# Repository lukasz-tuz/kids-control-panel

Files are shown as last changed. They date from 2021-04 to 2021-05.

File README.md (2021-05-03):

# kids-control-panel

This project is a spaceship-like control panel toy for kids (of all ages) allowing to:

* display characters from the alphanumeric keypad on the 7-segment display
* turn on LEDs in the 8x8 matrix when keys are pressed on the 4x4 keypad
* display some patterns using the 4-color LED bar
* use four tactile buttons to switch modes of operation for joystick and encoder:
  * control the LED bar
  * control the RGB LED's color
  * control LEDs on the 8x8 matrix
  
Repository contains FreeCAD designs for the casing (inteded for wood laser cutters), KiCAD schematics for the electronics part, and code for Arduino Uno R3 board.

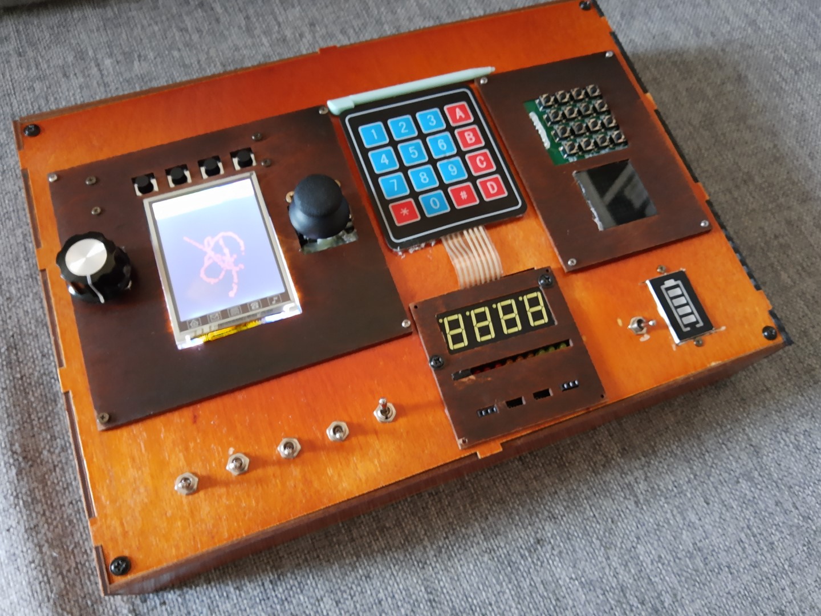
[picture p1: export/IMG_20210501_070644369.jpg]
Control panel Assembled control panel

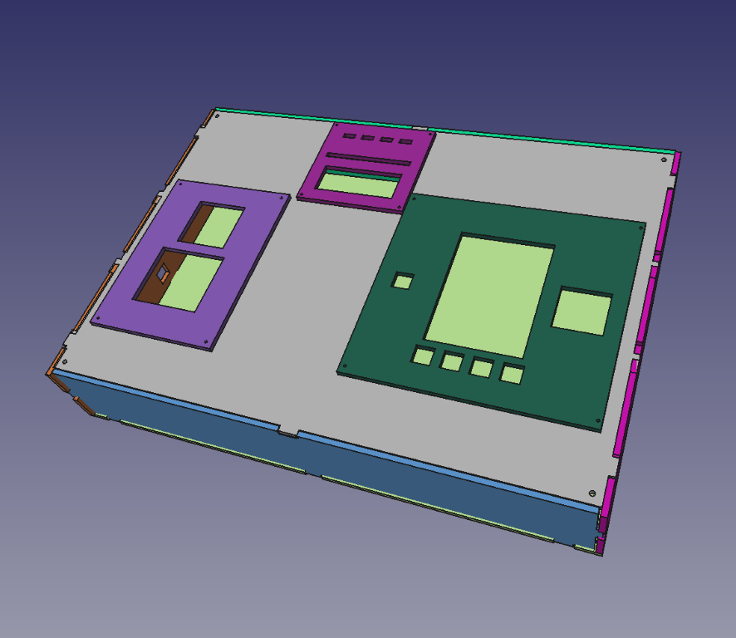
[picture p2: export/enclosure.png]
The casing Casing CAD design

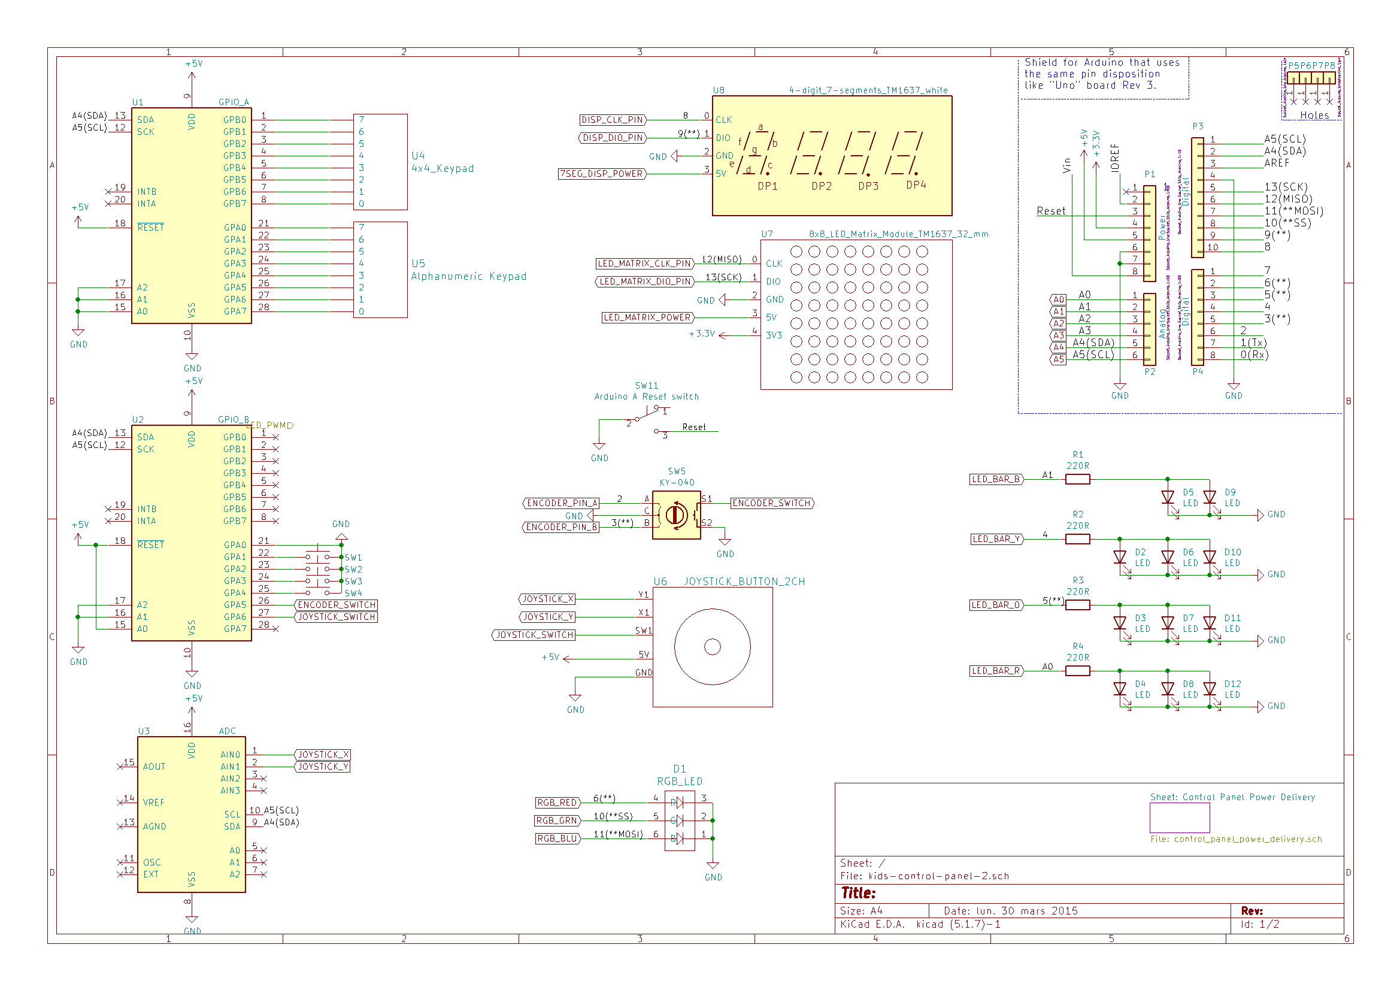
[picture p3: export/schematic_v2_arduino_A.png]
Schematic Schematic for Arduino wiring


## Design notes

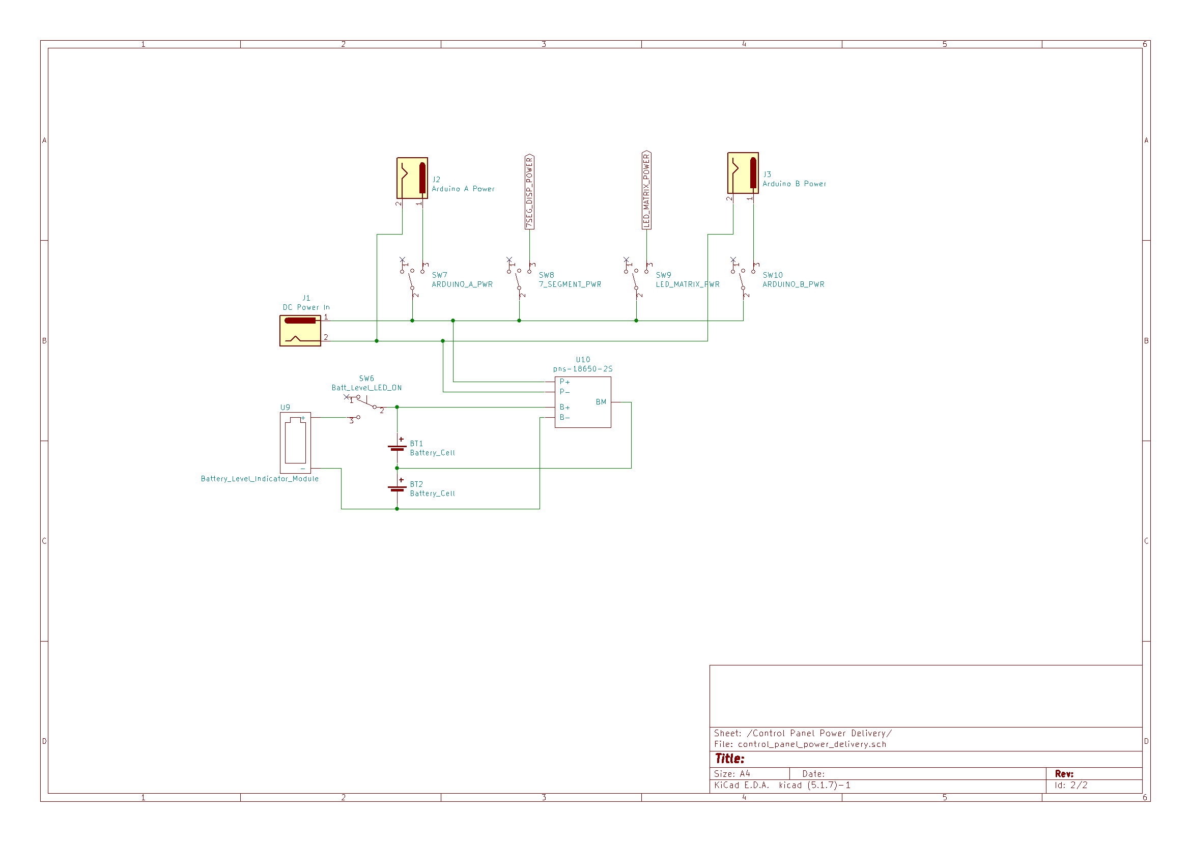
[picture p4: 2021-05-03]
export/schematic_power_connector.png

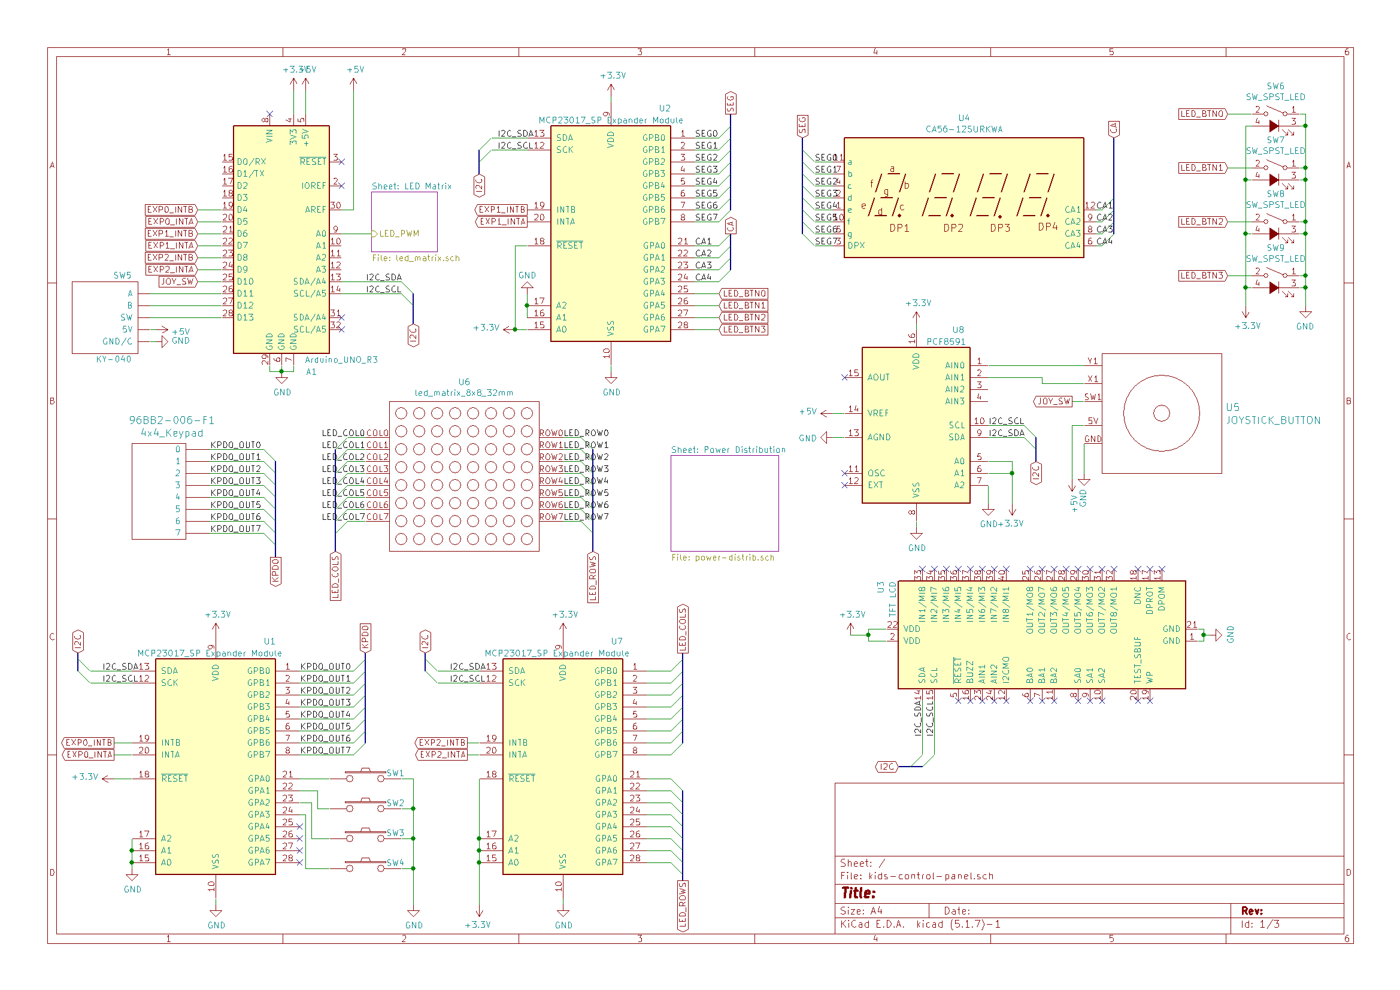
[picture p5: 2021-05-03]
export/schematic.png

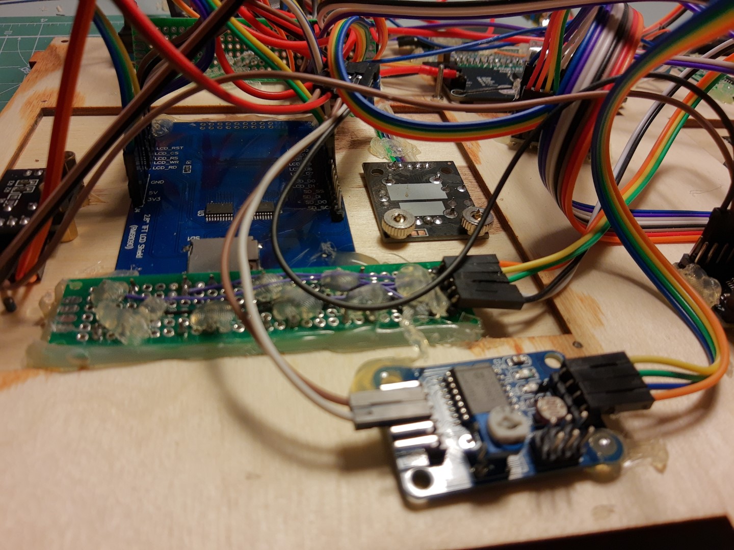
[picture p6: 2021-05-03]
export/IMG_20210430_232544490_MP.jpg

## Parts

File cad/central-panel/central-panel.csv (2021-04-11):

Comment | Designator | Footprint | LCSC
100pF | C1,C2 | Capacitor_SMD:C_0603_1608Metric | C1635
100uF | C3 | Capacitor_SMD:C_1206_3216Metric | C15008
10nF | C4 | Capacitor_SMD:C_0603_1608Metric | C57112
LED | D1,D2,D3,D4,D5,D6,D7,D8,D9,D10,D11,D12 | LED_SMD:LED_0603_1608Metric | C72038
LED_EN_A | D13 | LED_SMD:LED_Inolux_IN-PI554FCH_PLCC4_5.0x5.0mm_P3.2mm | C139127
LED_EN_B | D14 | LED_SMD:LED_Inolux_IN-PI554FCH_PLCC4_5.0x5.0mm_P3.2mm | C139127
MountingHole | H1,H2,H3,H4 | MountingHole:MountingHole_2.2mm_M2
Conn_01x06 | J1 | Connector_PinHeader_2.54mm:PinHeader_1x06_P2.54mm_Horizontal
Arduino_Conn | J4 | Connector_PinHeader_2.54mm:PinHeader_1x06_P2.54mm_Horizontal
220 | R1,R2,R3,R4 | Resistor_SMD:R_0603_1608Metric | C22962
10k | R5,R6 | Resistor_SMD:R_0603_1608Metric | C25804
SW_SPST_LED | SW1,SW2 | Connector_PinSocket_2.54mm:PinSocket_1x03_P2.54mm_Vertical
TestPoint | TP1,TP2,TP3,TP4,TP5,TP6 | TestPoint:TestPoint_Plated_Hole_D2.0mm
CA56-12EWA | U1 | Display_7Segment:CA56-12EWA
TM1637 | U2 | Package_SO:SOP-20_7.5x12.8mm_P1.27mm | C20001

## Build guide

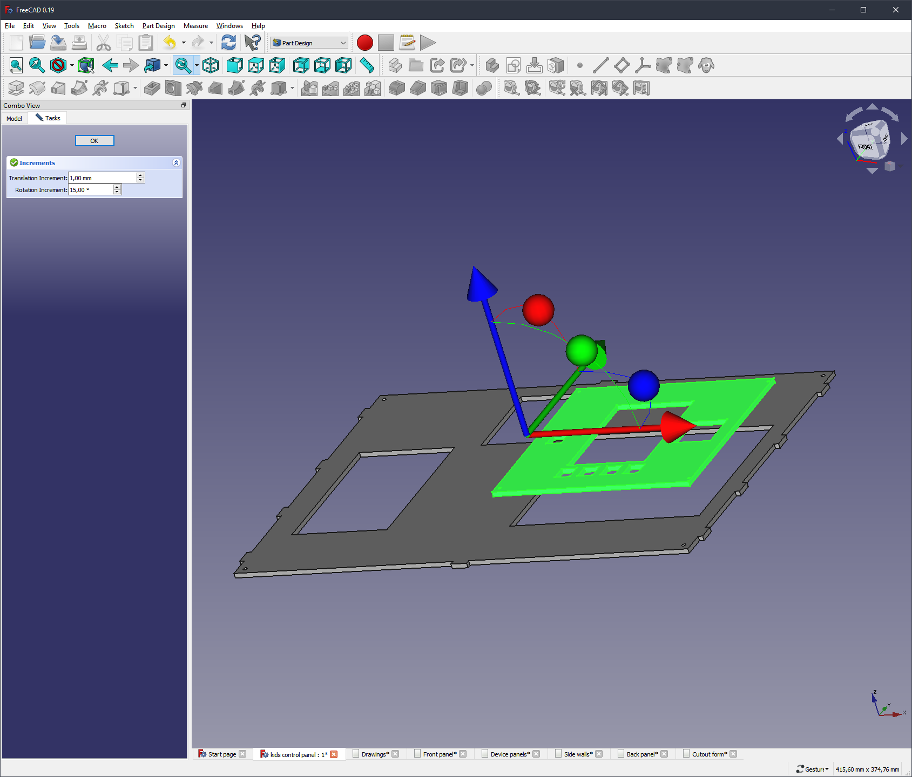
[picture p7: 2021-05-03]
export/step2-front panel transform.png

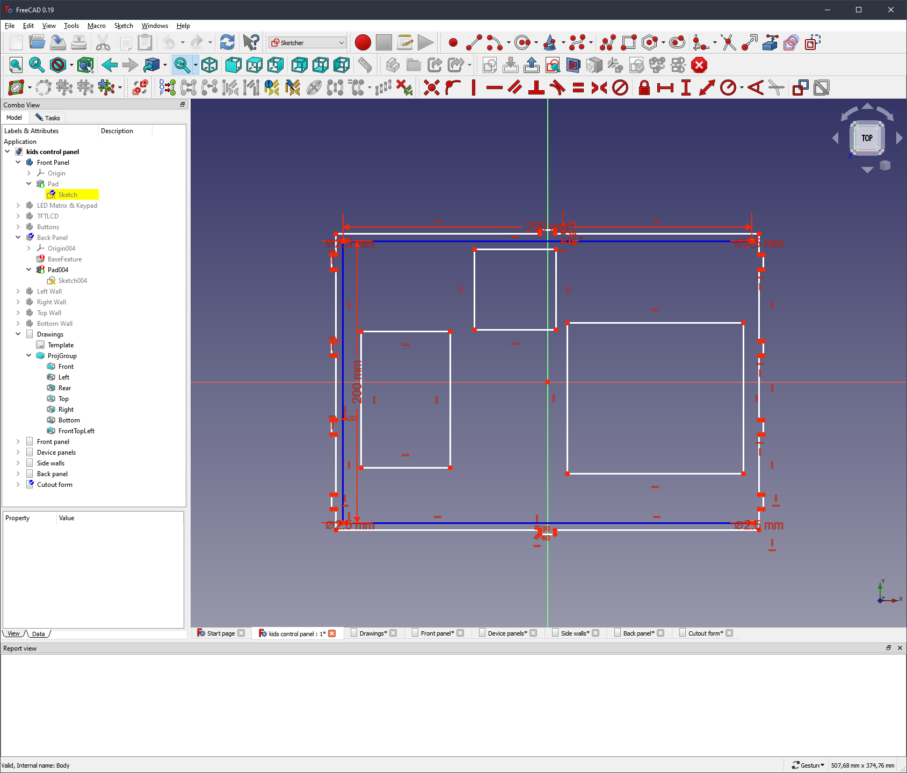
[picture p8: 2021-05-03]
export/step2-front panel sketch.png

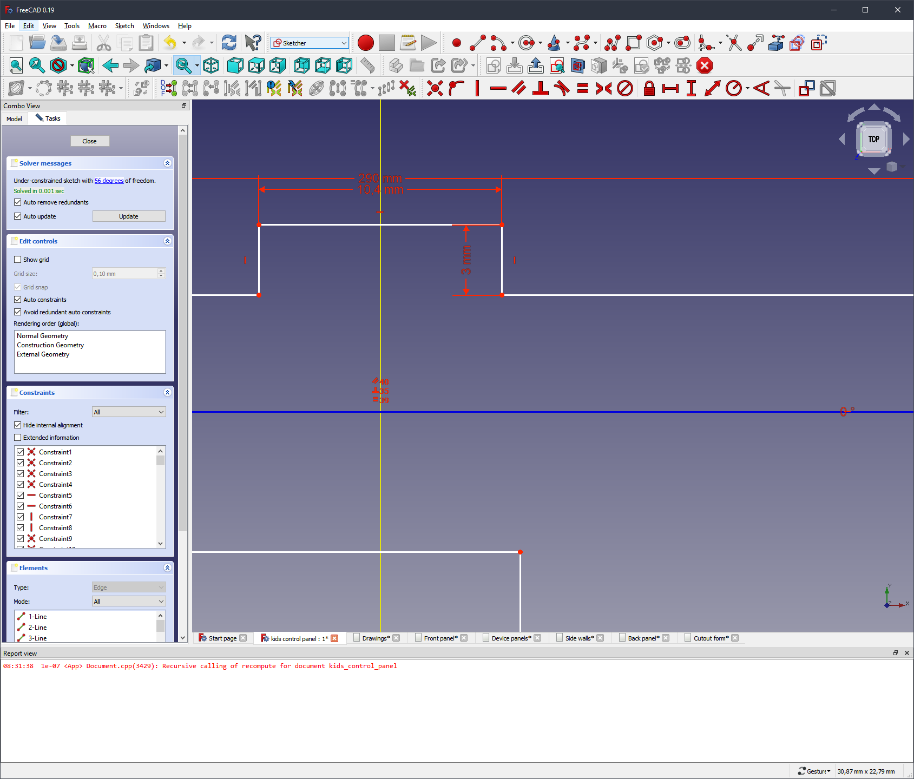
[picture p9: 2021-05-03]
export/step2-fron panel notch details.png

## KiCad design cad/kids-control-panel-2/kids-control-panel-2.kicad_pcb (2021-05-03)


Board: 2 copper layers, 68.6 x 53.3 mm, 8 parts (0 on the bottom side), 3 nets, no tracks yet.

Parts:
P1: Power; Socket_Strip_Arduino_1x08
P2: Analog; Socket_Strip_Arduino_1x06
P3: Digital; Socket_Strip_Arduino_1x10
P4: Digital; Socket_Strip_Arduino_1x08
P5, P6, P7, P8: CONN_01X01; Arduino_1pin

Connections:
/A4(SDA): P2.5, P3.2
/A5(SCL): P2.6, P3.1
GND: P1.6, P1.7, P3.4

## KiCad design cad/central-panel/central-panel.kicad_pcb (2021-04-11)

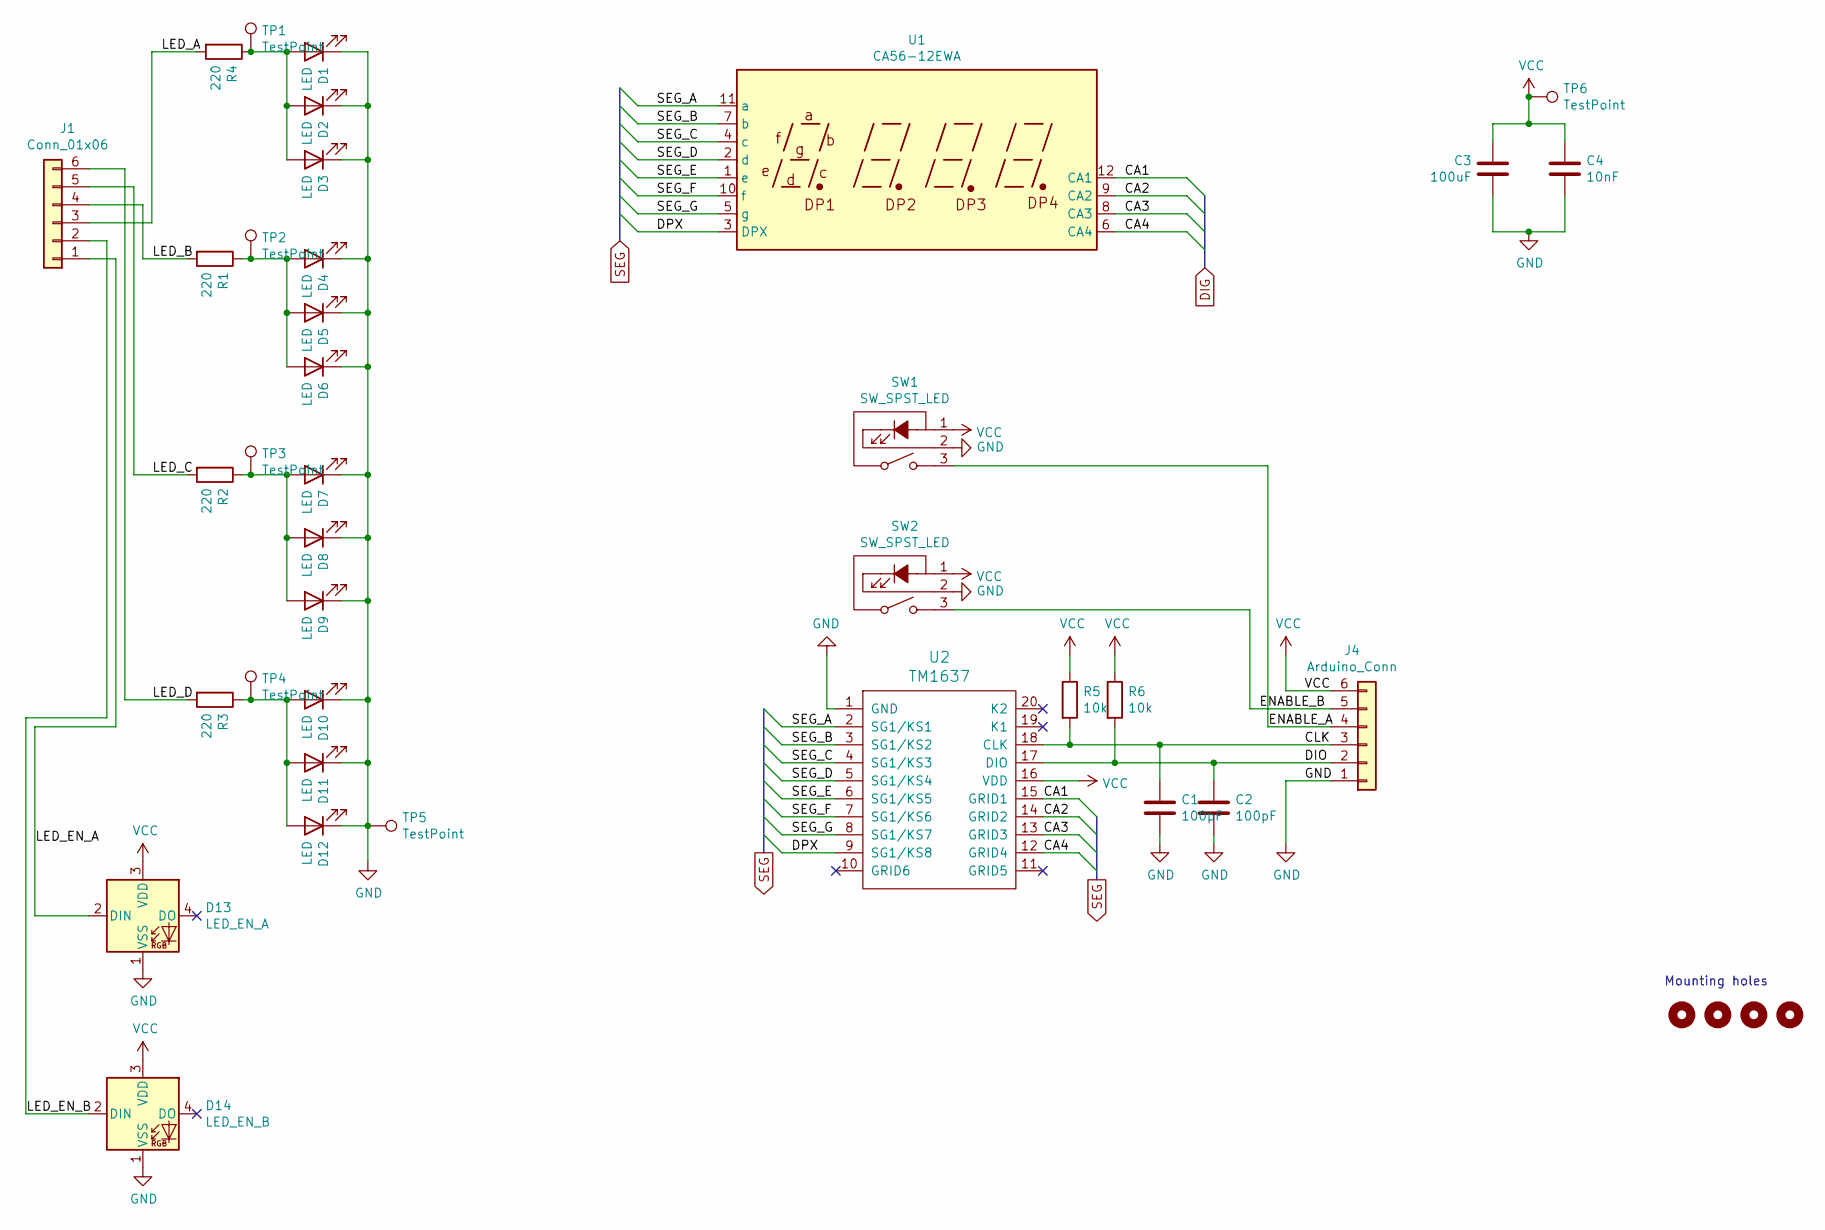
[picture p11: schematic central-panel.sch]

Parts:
C1, C2: 100pF; C_0603_1608Metric; LCSC C1635
C3: 100uF; C_1206_3216Metric; LCSC C15008
C4: 10nF; C_0603_1608Metric; LCSC C57112
D1, D2, D3: LED; LED_0603_1608Metric; LCSC C72038
D4, D5, D6: LED; LED_0603_1608Metric; LCSC C72043
D7, D8, D9: LED; LED_0603_1608Metric; LCSC C2286
D10, D11, D12: LED; LED_0603_1608Metric; LCSC C72041
D13: LED_EN_A; LED_Inolux_IN-PI554FCH_PLCC4_5.0x5.0mm_P3.2mm; LCSC C139127
D14: LED_EN_B; LED_Inolux_IN-PI554FCH_PLCC4_5.0x5.0mm_P3.2mm; LCSC C139127
H1, H2, H3, H4: MountingHole; MountingHole_2.2mm_M2
J1: Conn_01x06; PinHeader_1x06_P2.54mm_Horizontal
J4: Arduino_Conn; PinHeader_1x06_P2.54mm_Horizontal
R1, R2, R3, R4: 220; R_0603_1608Metric; LCSC C22962
R5, R6: 10k; R_0603_1608Metric; LCSC C25804
SW1, SW2: SW_SPST_LED; PinSocket_1x03_P2.54mm_Vertical
TP1, TP2, TP3, TP4, TP5, TP6: TestPoint; TestPoint_Plated_Hole_D2.0mm
U1: CA56-12EWA
U2: TM1637; SOP-20_7.5x12.8mm_P1.27mm; LCSC C20001

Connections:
/CA1: U1.12 (CA1), U2.15 (GRID1)
/CA2: U1.9 (CA2), U2.14 (GRID2)
/CA3: U1.8 (CA3), U2.13 (GRID3)
/CA4: U1.6 (CA4), U2.12 (GRID4)
/CLK: C1.1, J4.3, R5.2, U2.18 (CLK)
/DIO: C2.1, J4.2, R6.2, U2.17 (DIO)
/DPX: U1.3 (DPX), U2.9 (SG1/KS8)
/ENABLE_A: J4.4, SW1.3 (K)
/ENABLE_B: J4.5, SW2.3 (K)
/LED_A: J1.3, R4.2
/LED_B: J1.4, R1.2
/LED_C: J1.5, R2.2
/LED_D: J1.6, R3.2
/LED_EN_A: D13.2 (DIN), J1.1
/LED_EN_B: D14.2 (DIN), J1.2
/SEG_A: U1.11 (a), U2.2 (SG1/KS1)
/SEG_B: U1.7 (b), U2.3 (SG1/KS2)
/SEG_C: U1.4 (c), U2.4 (SG1/KS3)
/SEG_D: U1.2 (d), U2.5 (SG1/KS4)
/SEG_E: U1.1 (e), U2.6 (SG1/KS5)
/SEG_F: U1.10 (f), U2.7 (SG1/KS6)
/SEG_G: U1.5 (g), U2.8 (SG1/KS7)
GND: C1.2, C2.2, C3.2, C4.2, D1.1 (K), D2.1 (K), D3.1 (K), D4.1 (K), D5.1 (K), D6.1 (K), D7.1 (K), D8.1 (K), D9.1 (K), D10.1 (K), D11.1 (K), D12.1 (K), D13.1 (VSS), D14.1 (VSS), J4.1, SW1.2, SW2.2, TP5.1, U2.1 (GND)
unnamed: D1.2 (A), D2.2 (A), D3.2 (A), R4.1, TP1.1
unnamed: D4.2 (A), D5.2 (A), D6.2 (A), R1.1, TP2.1
unnamed: D7.2 (A), D8.2 (A), D9.2 (A), R2.1, TP3.1
unnamed: D10.2 (A), D11.2 (A), D12.2 (A), R3.1, TP4.1
VCC: C3.1, C4.1, D13.3 (VDD), D14.3 (VDD), J4.6, R5.1, R6.1, SW1.1, SW2.1, TP6.1, U2.16 (VDD)

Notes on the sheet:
Mounting holes

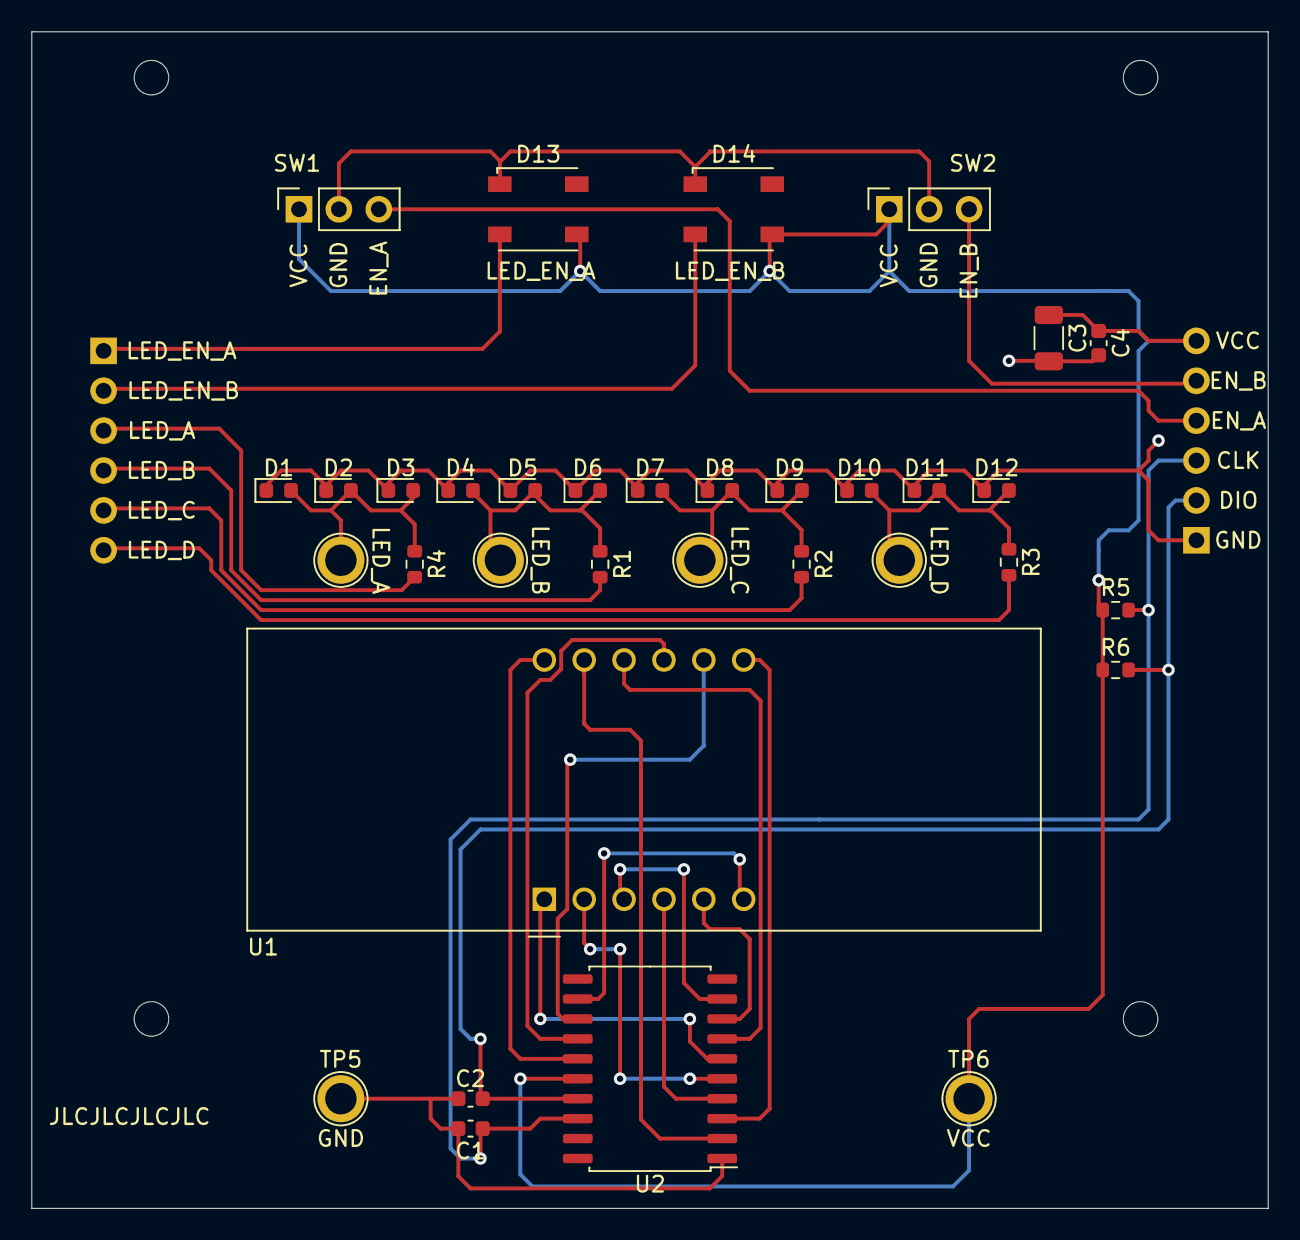
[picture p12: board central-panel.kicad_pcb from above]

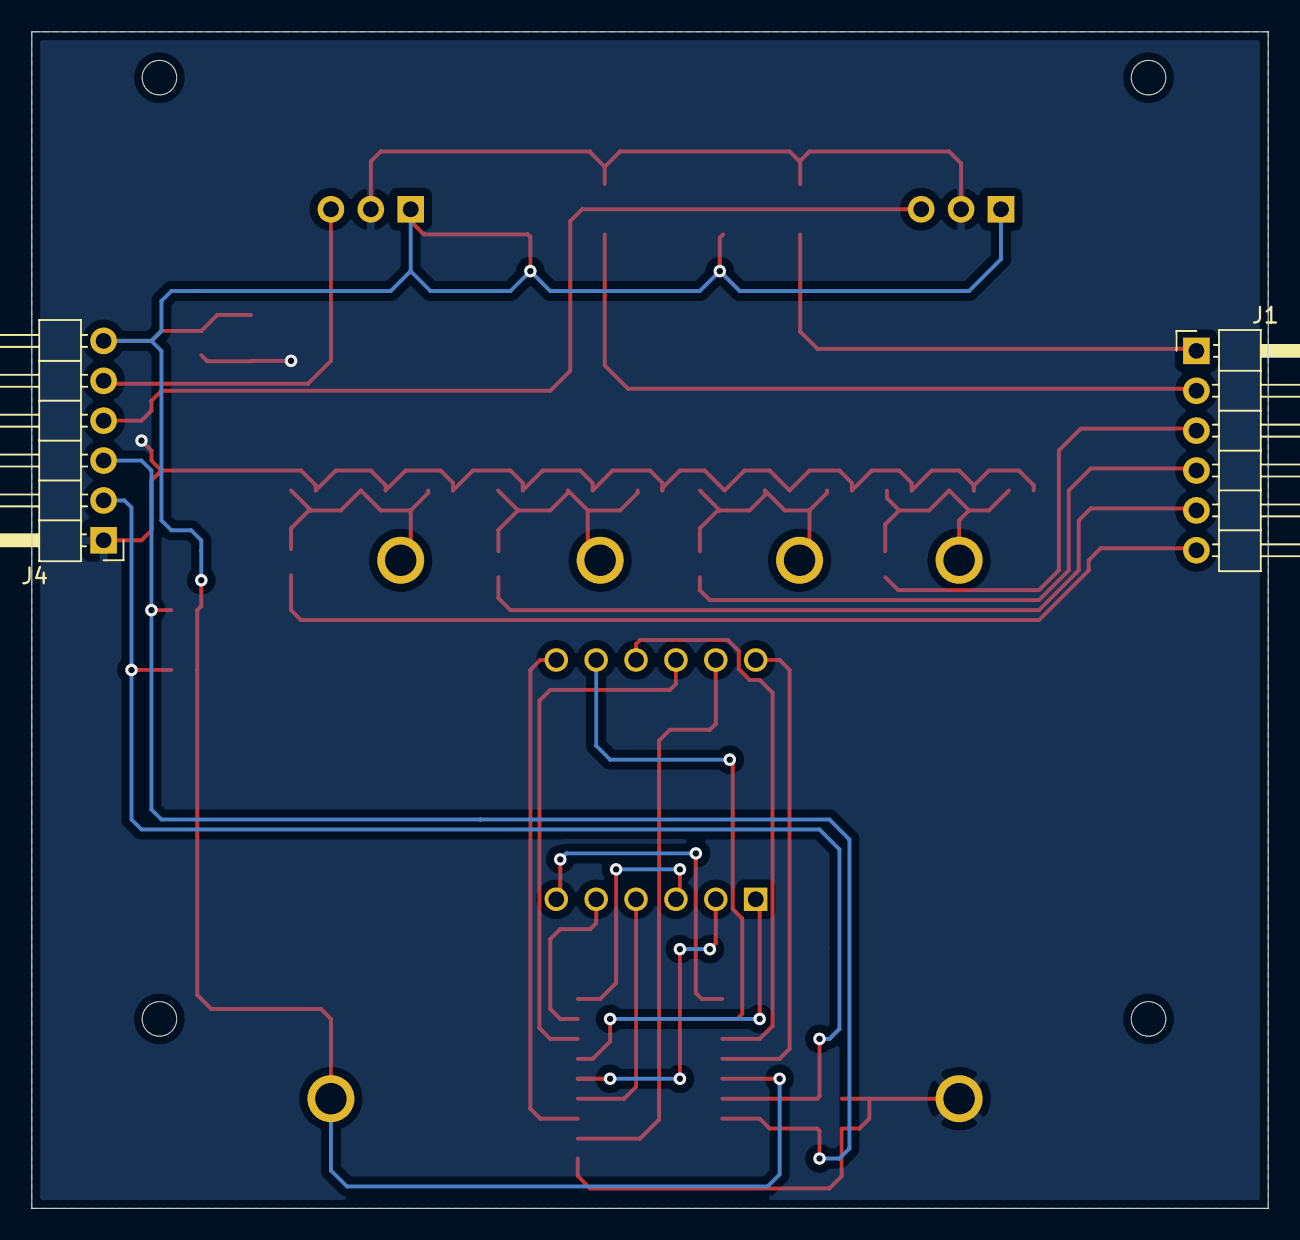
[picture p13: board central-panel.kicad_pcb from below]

Board: 2 copper layers, 78.7 x 74.9 mm, 40 parts (2 on the bottom side), 28 nets.

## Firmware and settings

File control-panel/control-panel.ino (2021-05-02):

#include <Arduino.h>
#include <Encoder.h>
#include <Adafruit_MCP23017.h>
#include <TM1637Display.h>

#include "controlpanel.h"

#ifdef LCD_TFT_CONNECTED
#include <MCUFRIEND_kbv.h>
MCUFRIEND_kbv tft; // hard-wired for UNO shields anyway.
#include <TouchScreen.h>
#endif

#ifdef RGB_LED_CONNECTED
#include "controlpanel_rgbled.h"
#endif

#include "controlpanel_display.h"
#include "controlpanel_keypad.h"
#include "controlpanel_ledbar.h"
#include "controlpanel_joystick.h"

/**
  From Arduino I2C examples.
  Scan I2C bus for devices, print addresses on Serial.
 */
void _scanI2C()
{
  uint8_t nDevices = 0;

  for (byte address = 1; address < 127; ++address)
  {
    // The i2c_scanner uses the return value of
    // the Write.endTransmisstion to see if
    // a device did acknowledge to the address.
    Wire.beginTransmission(address);
    byte error = Wire.endTransmission();

    if (error == 0)
    {
      Serial.print("I2C device found at address 0x");
      if (address < 16)
      {
        Serial.print("0");
      }
      Serial.print(address, HEX);
      Serial.println("  !");

      ++nDevices;
    }
    else if (error == 4)
    {
      Serial.print("Unknown error at address 0x");
      if (address < 16)
      {
        Serial.print("0");
      }
      Serial.println(address, HEX);
    }
  }
  if (nDevices == 0)
  {
    Serial.println("No I2C devices found\n");
  }
  else
  {
    Serial.println("done\n");
  }
}

/**
 * @brief Convert a character based control mode selection into
 * an encoded value.
 *
 * @param b Character received from input device
 * @return uint8_t uint8 encoded control mode for the panel.
 */
uint8_t get_controls_mode(char b)
{
  uint8_t mode;

  switch (b)
  {
  case 'X':
    mode = RGB_LED_MODE;
    break;
  case 'Y':
    mode = LED_BAR_MODE;
    break;
  case 'Z':
    mode = LED_MATRIX_MODE;
    break;
  case '@':
    mode = LCD_MODE;
    break;
  default:
    mode = DEFAULT_MODE;
    break;
  }

  return mode;
}

/**
 * @brief Increment/decrement value with wrap around at value defined by size.
 *
 * If incrementing (direction > 0), value will wrap around to zero when specified
 * size is reached.
 *
 * If decrementing (direction < 0), value wraps around to size - 1 when zero is reached.
 *
 * @param value Value to be modified.
 * @param direction Determines if value is to be incremented or decremented.
 * @param size Size at which value is to be wrapped.
 * @return uint8_t Modified value.
 */
uint8_t wrap_around(uint8_t value, int direction, uint8_t size)
{
  uint8_t v = value;

  if (direction > 0)
  {
    ++v %= size;
  }

  if (direction < 0)
  {
    if (v == 0)
    {
      v = size;
    }
    v--;
  }
  return v;
}

#ifdef RGB_LED_CONNECTED
using namespace rgbled;
#endif
using namespace joystick;

/*
Instantiate objects for control panel's internals.

GPIO Expanders go first.
*/
auto gpiosA = new Adafruit_MCP23017();
auto gpiosB = new Adafruit_MCP23017();
Adafruit_PCF8591 adc = Adafruit_PCF8591();

// /* Keypad panel control objects */
PanelKeypad alpha_keypad = PanelKeypad(gpiosA, makeKeymap(alphanumeric), rowPins, colPins, rows, cols);
PanelKeypad matrix_keypad = PanelKeypad(gpiosA, makeKeymap(matrix), matrixRowPins, matrixColPins, rows, cols);
PanelKeypad button_keypad = PanelKeypad(gpiosB, makeKeymap(buttons), buttonRowPins, buttonColPins, buttonsRows, buttonsCols);

// /* Rotary encoder */
Encoder knob = Encoder(ENCODER_PIN_A, ENCODER_PIN_B);

// /* Joystick */
Joystick joy = Joystick(&adc, JOYSTICK_X, JOYSTICK_Y);

// /* Displays */
TM1637Display seven_seg = TM1637Display(DISP_CLK_PIN, DISP_DIO_PIN);
uint8_t seven_seg_brightness = 3;

TM1637Display led_matrix = TM1637Display(LED_MATRIX_CLK_PIN, LED_MATRIX_DIO_PIN);
uint8_t led_matrix_brightness = 3;

// /* Common wrappers for hardware-specific objects */
Display char_disp = Display(DISPLAY_SIZE);
Display matrix_disp = Display(LED_MATRIX_SIZE);

#ifdef RGB_LED_CONNECTED
// /* The RGB LED module */
RgbLed rgb_led = RgbLed(RBG_RED, RGB_GRN, RGB_BLU);
#endif

/* Custom LED bar module */
LedBar led_bar = LedBar(LED_BAR_Y, LED_BAR_O, LED_BAR_R, LED_BAR_B);

#ifdef LCD_TFT_CONNECTED
/* The TFT LCD display shield with touch*/
TouchScreen ts = TouchScreen(XP, YP, XM, YM, 300);

/**
 * @brief Global variable for storing coordinates for point pressed on screen.
 *
 */
TSPoint tp;

/**
 * @brief TFT LCD shield control variables.
 *
 */
int16_t BOXSIZE; // Size of color picker boxes, calculated in setup()
int16_t PENRADIUS = 2;
uint16_t ID, oldcolor, currentcolor;
uint8_t Orientation = 0; // PORTRAIT
#endif

/**
 * @brief Mode determines which modules are controlled by joystick and encoder.
 * Mode is swtiched on user input. @see pushbutton.
 *
 */
uint8_t current_mode = DEFAULT_MODE;

/**
 * @brief Last recorded position of rotary encoder, used to determine rotation direction.
 *
 */
int last_knob_position = 0;

#ifdef RGB_LED_CONNECTED
/**
 * @brief Selected color for RGB LED module.
 *
 */
Color stored_rgb_led = Color(0, 0, 0);
#endif

/**
 * @brief Internal display buffer for LED matrix module.
 *
 */
uint8_t led_matrix_buffer[LED_MATRIX_SIZE] = {0};
uint8_t coord_x = 0;
uint8_t coord_y = 0;

/**
 * @brief When set, locks changes of coord_x/coord_y variables on subsequent calls for loop().
 *
 */
bool coords_update = false;

#ifdef LCD_TFT_CONNECTED
void setup_tft()
{
  /* Setup TFT LCD screen */
  uint16_t tmp;

  tft.reset();
  ID = tft.readID();
  tft.begin(ID);
  tft.setRotation(Orientation);
  tft.fillScreen(BLACK);

  BOXSIZE = tft.width() / 6;
  tft.fillScreen(BLACK);
  tft.fillRect(0, 0, BOXSIZE, BOXSIZE, RED);
  tft.fillRect(BOXSIZE, 0, BOXSIZE, BOXSIZE, YELLOW);
  tft.fillRect(BOXSIZE * 2, 0, BOXSIZE, BOXSIZE, GREEN);
  tft.fillRect(BOXSIZE * 3, 0, BOXSIZE, BOXSIZE, CYAN);
  tft.fillRect(BOXSIZE * 4, 0, BOXSIZE, BOXSIZE, BLUE);
  tft.fillRect(BOXSIZE * 5, 0, BOXSIZE, BOXSIZE, MAGENTA);

  tft.drawRect(0, 0, BOXSIZE, BOXSIZE, WHITE);
  currentcolor = RED;
  delay(1000);
}

/**
 * @brief Loop for paint app displayed on TFT LCD shield. Also handles touch input.
 *
 */
void loop_tft()
{
  uint16_t xpos, ypos; //screen coordinates
  tp = ts.getPoint();  //tp.x, tp.y are ADC values

  // we have some minimum pressure we consider 'valid'
  // pressure of 0 means no pressing!
  if (tp.z > MINPRESSURE && tp.z < MAXPRESSURE)
  {
    // most mcufriend have touch (with icons) that extends below the TFT
    // screens without icons need to reserve a space for "erase"
    // scale the ADC values from ts.getPoint() to screen values e.g. 0-239
    //
    // Calibration is true for PORTRAIT. tp.y is always long dimension
    // map to your current pixel orientation
    switch (Orientation)
    {
    case 0:
      xpos = map(tp.x, TS_LEFT, TS_RT, 0, tft.width());
      ypos = map(tp.y, TS_TOP, TS_BOT, 0, tft.height());
      break;
    case 1:
      xpos = map(tp.y, TS_TOP, TS_BOT, 0, tft.width());
      ypos = map(tp.x, TS_RT, TS_LEFT, 0, tft.height());
      break;
    case 2:
      xpos = map(tp.x, TS_RT, TS_LEFT, 0, tft.width());
      ypos = map(tp.y, TS_BOT, TS_TOP, 0, tft.height());
      break;
    case 3:
      xpos = map(tp.y, TS_BOT, TS_TOP, 0, tft.width());
      ypos = map(tp.x, TS_LEFT, TS_RT, 0, tft.height());
      break;
    }

    // are we in top color box area ?
    if (ypos < BOXSIZE)
    { //draw white border on selected color box
      oldcolor = currentcolor;

      if (xpos < BOXSIZE)
      {
        currentcolor = RED;
        tft.drawRect(0, 0, BOXSIZE, BOXSIZE, WHITE);
      }
      else if (xpos < BOXSIZE * 2)
      {
        currentcolor = YELLOW;
        tft.drawRect(BOXSIZE, 0, BOXSIZE, BOXSIZE, WHITE);
      }
      else if (xpos < BOXSIZE * 3)
      {
        currentcolor = GREEN;
        tft.drawRect(BOXSIZE * 2, 0, BOXSIZE, BOXSIZE, WHITE);
      }
      else if (xpos < BOXSIZE * 4)
      {
        currentcolor = CYAN;
        tft.drawRect(BOXSIZE * 3, 0, BOXSIZE, BOXSIZE, WHITE);
      }
      else if (xpos < BOXSIZE * 5)
      {
        currentcolor = BLUE;
        tft.drawRect(BOXSIZE * 4, 0, BOXSIZE, BOXSIZE, WHITE);
      }
      else if (xpos < BOXSIZE * 6)
      {
        currentcolor = MAGENTA;
        tft.drawRect(BOXSIZE * 5, 0, BOXSIZE, BOXSIZE, WHITE);
      }

      if (oldcolor != currentcolor)
      { //rub out the previous white border
        if (oldcolor == RED)
          tft.fillRect(0, 0, BOXSIZE, BOXSIZE, RED);
        if (oldcolor == YELLOW)
          tft.fillRect(BOXSIZE, 0, BOXSIZE, BOXSIZE, YELLOW);
        if (oldcolor == GREEN)
          tft.fillRect(BOXSIZE * 2, 0, BOXSIZE, BOXSIZE, GREEN);
        if (oldcolor == CYAN)
          tft.fillRect(BOXSIZE * 3, 0, BOXSIZE, BOXSIZE, CYAN);
        if (oldcolor == BLUE)
          tft.fillRect(BOXSIZE * 4, 0, BOXSIZE, BOXSIZE, BLUE);
        if (oldcolor == MAGENTA)
          tft.fillRect(BOXSIZE * 5, 0, BOXSIZE, BOXSIZE, MAGENTA);
      }
    }
    // are we in drawing area ?
    if (((ypos - PENRADIUS) > BOXSIZE) && ((ypos + PENRADIUS) < tft.height()))
    {
      tft.fillCircle(xpos, ypos, PENRADIUS, currentcolor);
    }
    // are we in erase area ?
    // Plain Touch panels use bottom 10 pixels e.g. > h - 10
    // Touch panels with icon area e.g. > h - 0
    if (ypos > tft.height() - 10)
    {
      // press the bottom of the screen to erase
      tft.fillRect(0, BOXSIZE, tft.width(), tft.height() - BOXSIZE, BLACK);
    }
  }
}
#endif

void setup()
{
  Wire.begin();
  Serial.begin(115200);
  while (!Serial)
    ; // Leonardo: wait for serial monitor
  Serial.println("Initialzing...");

#ifdef LCD_TFT_CONNECTED
  setup_tft();
#endif

  // I2C scan only called for debug purposes.
  _scanI2C();

  gpiosA->begin(GPIOA_ADDR, &Wire);
  gpiosB->begin(GPIOB_ADDR, &Wire);
  adc.begin();

  // Configure pins for buttons/switches which are not part of
  // scanning keypad matrix.
  _configurePins(gpiosB, JOYSTICK_SWITCH, INPUT_PULLUP);
  _configurePins(gpiosB, ENCODER_SWITCH, INPUT_PULLUP);
  _configurePins(gpiosB, ENABLE_A_PIN, INPUT_PULLUP);
  _configurePins(gpiosB, ENABLE_B_PIN, INPUT_PULLUP);

  // Initialize displays
  seven_seg.setBrightness(seven_seg_brightness, true);
  seven_seg.clear();

  led_matrix.setBrightness(led_matrix_brightness, true);
  led_matrix.clear();

  led_bar.off();

  rgb_led.setColor(Color(0.5, 0.5, 0.5));
}

/**
 * @brief Handler for LED matrix controls by encoder and joystick
 *
 */
void led_matrix_handler()
{
  /*
    If joystick is pushed in either direction, update display.
  */
  if (joy.isTilted(0.6) and coords_update == false)
  {
    // Lock update so that each push of joystick only moves LEDs by one
    coords_update = true;

    // don't update coordinates in getX/getY calls, just use ones already done.
    int direction_x = joy.getDirection(joy.getX(false), false);
    coord_x = wrap_around(coord_x, direction_x, LED_MATRIX_SIZE);
    int direction_y = joy.getDirection(joy.getY(false), false);
    coord_y = wrap_around(coord_y, direction_y, LED_MATRIX_SIZE);

    // XOR operation done so that LEDs can be switched on/off
    led_matrix_buffer[coord_x] ^= (1 << coord_y);
    led_matrix.setSegments(led_matrix_buffer, LED_MATRIX_SIZE);
  }
  else if (!joy.isTilted(0.1) and coords_update == true)
  {
    // Joystick in neutral position, release lock
    coords_update = false;
  }
}

#ifdef RGB_LED_CONNECTED
/**
 * @brief Handler for RGB LED controls by encoder and joystick.
 *
 * @param joy_sw State of joystick switch.
 * @param delta State of Encoder knob
 */
void rgb_led_handler(byte joy_sw, int delta)
{
  // Map raw values from joy_x/_y to [-1:1] range
  if (joy.isTilted(0.1))
  {
    // If joystick is not in neutral position, update LED's color
    // according to (x,y) coordinates.
    float joy_x = joy.getX(false);
    float joy_y = joy.getY(false);

    uint32_t rgb = rgb_led.rectToRGB(joy_x, joy_y);
    rgb_led.setColor(rgb);

    // Store selected color
    if (joy_sw == 0)
    {
      stored_rgb_led.raw_32 = rgb;
    }
  }
  else
  {
    // Update RGB LED's brightness
    if (delta != 0)
    {
      rgb_led.changeBrightness(delta);
      stored_rgb_led = rgb_led.getColor();
    }
    // Show stored color when joystick is in neutral position.
    rgb_led.setColor(stored_rgb_led);
  }
}
#endif

/**
 * @brief Main loop for control panel.
 *
 */
void loop()
{
  // Read state of Enable pins
  byte enable_a = gpiosB->digitalRead(ENABLE_A_PIN);
  byte enable_b = gpiosB->digitalRead(ENABLE_B_PIN);

  if (true)
  {
    // Process paint app first.
#ifdef LCD_TFT_CONNECTED
    // Initialize shared pins to SPI mode
    pinMode(MISO, INPUT_PULLUP);
    pinMode(MOSI, OUTPUT);
    // if sharing pins, you'll need to fix the directions of the touchscreen pins
    pinMode(XM, OUTPUT);
    pinMode(YP, OUTPUT);

    loop_tft();

    // Restore SPI pins to GPIO mode
    pinMode(MISO, OUTPUT); // pin 12, LED_BAR_R by default
    pinMode(MOSI, INPUT);  // pin 11, LED_MATRIX_DIO_PIN by default
                           // No need to restore A4 as both SPI and rest of device is OUTPUT
#endif

    // Poll aplhanumeric keypad, key matrix, buttons, joystick, encoder
    char character = alpha_keypad.getKey();
    char matrix_key = matrix_keypad.getKey();
    char pushbutton = button_keypad.getKey();
    byte joy_sw = gpiosB->digitalRead(JOYSTICK_SWITCH);
    byte enc_sw = gpiosB->digitalRead(ENCODER_SWITCH);
    int position = knob.read();
    int delta = position - last_knob_position;
    last_knob_position = position;

    if (pushbutton != NO_KEY)
    {
      uint8_t mode = get_controls_mode(pushbutton);
      if (mode != current_mode)
      {
        Serial.print("Switching mode to ");
        Serial.println(mode);
        current_mode = mode;

        // Do some initialization work for different modes.
        if (mode == LED_MATRIX_MODE)
        {
          led_matrix.clear();
        }
        else if (mode == LED_BAR_MODE)
        {
          matrix_disp.clear();
          led_bar.off();
        }
      }
    }

    if (current_mode == RGB_LED_MODE)
    {
#ifdef RGB_LED_CONNECTED
      rgb_led_handler(joy_sw, delta);
#endif
      led_bar.move_bar(1);
    }
    else if (current_mode == LED_BAR_MODE)
    {
      led_bar.move_bar(delta);
    }
    else if (current_mode == LED_MATRIX_MODE)
    {
      led_matrix_handler();
    }
    else if (current_mode == LCD_MODE)
    {
    }

    if (character != NO_KEY)
    {
      // Update 7seg display
      char_disp.set_character(character);
      seven_seg.setSegments(char_disp.get_buffer(), DISPLAY_SIZE);
      Serial.println(character);
    }

    if (matrix_key != NO_KEY)
    {
      // Update LED matrix
      matrix_disp.set_character(matrix_key);
      led_matrix.setSegments(matrix_disp.get_buffer(), LED_MATRIX_SIZE);
      Serial.println(matrix_key);
    }
  }
#ifdef LCD_TFT_CONNECTED
  else
  {
    tft.fillScreen(BLACK);
  }
#endif
}

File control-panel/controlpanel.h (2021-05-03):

#include <Adafruit_MCP23017.h>

/**
 * @brief Wrapper for configuring GPIO pins behind MCP23017 I2C IO expander.
 * 
 * @param gpios Pointer to Adafruit_MCP23017 instance associated with pins being configured.
 * @param pins {Array} Array of pin numbers _on expander instance defined by *gpios_ to configure.
 * @param num_pins Length of pins array, in bytes.
 * @param mode Mode (input/input_pullup/output) to which pins are to be configured.
 */
inline void _configurePins(Adafruit_MCP23017 *gpios, byte *pins, byte num_pins, byte mode)
{
    uint8_t mode_internal;
    switch (mode)
    {
    case OUTPUT:
        mode_internal = OUTPUT;
        break;
    case INPUT:
    case INPUT_PULLUP:
        mode_internal = INPUT;
        break;
    default:
        mode_internal = INPUT;
        break;
    }
    for (byte i = 0; i < num_pins; i++)
    {
        gpios->pinMode(pins[i], mode_internal);
        if (mode == INPUT_PULLUP)
            gpios->pullUp(pins[i], 1);
        else
            gpios->pullUp(pins[i], 0);
    }
}

/**
 * @brief Wrapper for configuring a GPIO pin on MCP23017 I2C IO expander.
 * 
 * @param gpios Pointer to Adafruit_MCP23017 instance associated with pins being configured.
 * @param pin Pin numbers _on expander instance defined by *gpios_ to configure.
 * @param mode Mode (input/input_pullup/output) to which pins are to be configured.
 */
inline void _configurePins(Adafruit_MCP23017 *gpios, byte pin, byte mode)
{
    uint8_t mode_internal;
    switch (mode)
    {
    case OUTPUT:
        mode_internal = OUTPUT;
        break;
    case INPUT:
    case INPUT_PULLUP:
        mode_internal = INPUT;
        break;
    default:
        mode_internal = INPUT;
        break;
    }
    gpios->pinMode(pin, mode_internal);
    if (mode == INPUT_PULLUP)
        gpios->pullUp(pin, 1);
    else
        gpios->pullUp(pin, 0);
}

/**
 * @brief Configures pin modes for an array of native Arduino GPIOs.
 * 
 * @param pins {Array} Array of pin numbers to configure.
 * @param num_pins Length of pins array, in bytes.
 * @param mode Mode (input/input_pullup/output) to which pins are to be configured.
 */
inline void _configurePins(byte *pins, byte num_pins, byte mode)
{
    for (byte i = 0; i < num_pins; i++)
    {
        pinMode(pins[i], mode);
    }
}

/**
 * @brief Wrapper for Arduino's native pinMode function.
 * 
 * @param pin Pin number to configure.
 * @param mode Mode to which configure selected pin.
 */
inline void _configurePins(byte pin, byte mode)
{
    pinMode(pin, mode);
}

/*
PINOUTS: ARDUINO UNO
                                      +-----+
         +----[PWR]-------------------| USB |--+
         |                            +-----+  |
         |         GND/RST2  [ ][ ]            |
         |       MOSI2/SCK2  [ ][ ]  A5/SCL[ ] |   C5 
         |          5V/MISO2 [ ][ ]  A4/SDA[ ] |   C4 
         |                             AREF[ ] |
         |                              GND[ ] |
         | [ ]N/C                    SCK/13[M] |   B5
         | [ ]IOREF                 MISO/12[M] |   .
         | [ ]RST                   MOSI/11[R]~|   .
         | [ ]3V3    +---+               10[R]~|   .
         | [ ]5v    -| A |-               9[S]~|   .
         | [ ]GND   -| R |-               8[S] |   B0
         | [ ]GND   -| D |-                    |
         | [ ]Vin   -| U |-               7[ ] |   D7
         |          -| I |-               6[R]~|   .
         | [L]A0    -| N |-               5[L]~|   .
         | [L]A1    -| O |-               4[L] |   .
         | [ ]A2     +---+           INT1/3[E]~|   .
         | [ ]A3                     INT0/2[E] |   .
         | [ ]A4/SDA  RST SCK MISO     TX>1[ ] |   .
         | [ ]A5/SCL  [ ] [ ] [ ]      RX<0[ ] |   D0
         |            [ ] [ ] [ ]              |
         |  UNO_R3    GND MOSI 5V  ____________/
          \_______________________/
   
   http://busyducks.com/ascii-art-arduinos

*/

// LED bar pins (L)
#define LED_BAR_Y (4)
#define LED_BAR_O (5)
#define LED_BAR_R (A0)
#define LED_BAR_B (A1)

// Rotary encoder pins (E)
#define ENCODER_PIN_A (2)
#define ENCODER_PIN_B (3)

// 7seg Display pins (S)
#define DISP_CLK_PIN (8)
#define DISP_DIO_PIN (9)

// LED Matrix pins (M)
#define LED_MATRIX_CLK_PIN (12)
#define LED_MATRIX_DIO_PIN (13)

// RGB LED pins - PWM required! (R)
#define RGB_LED_CONNECTED
#define RBG_RED (6)
#define RGB_GRN (10)
#define RGB_BLU (11)

// TFT LCD (T)
#undef LCD_TFT_CONNECTED
const int XP = (7), XM = A1, YP = A2, YM = (6); //240x320 ID=0x6809

/*
   GPIO Exander A
*/
// Alphanumeric keypad on GPIOA
const byte rows = 4;
const byte cols = 4;
char alphanumeric[rows][cols] = {
    {'1', '2', '3', 'A'},
    {'4', '5', '6', 'B'},
    {'7', '8', '9', 'C'},
    {'*', '0', '#', 'D'}};
byte colPins[rows] = {3, 2, 1, 0};
byte rowPins[cols] = {7, 6, 5, 4};

// 4x4 keypad on GPIOA
char matrix[rows][cols] = {
    {'0', '1', '2', '3'},
    {'4', '5', '6', '7'},
    {'8', '9', 'A', 'B'},
    {'C', 'D', 'E', 'F'}};
byte matrixRowPins[rows] = {11, 10, 9, 8};
byte matrixColPins[cols] = {15, 14, 13, 12};

/*
    GPIO Expander B
*/
// Pushbuttons on GPIOB
const byte buttonsRows = 1;
const byte buttonsCols = 4;
char buttons[buttonsRows][buttonsCols] = {'X', 'Y', 'Z', '@'};
byte buttonRowPins[buttonsRows] = {0};
byte buttonColPins[buttonsCols] = {1, 2, 3, 4};

// Pins for enable/disable touch buttons on gpioB
#define ENCODER_SWITCH (5)
#define JOYSTICK_SWITCH (6)

#define ENABLE_A_PIN (8)
#define ENABLE_B_PIN (9) 

/*
    ADC Expander A
*/
// Joystick pins on ADC
#define JOYSTICK_X (0)
#define JOYSTICK_Y (1)

/*
    CONFIGURATION SETTINGS
*/
// GPIO expander addresses
#define GPIOA_ADDR (0)
#define GPIOB_ADDR (1)

// 7-seg display size - 4-digit
#define DISPLAY_SIZE (4)

// LED matrix size - 8x8
#define LED_MATRIX_SIZE (8)

// TFT LCD
// Values hand calibrated for specific TFT LCD shield
const int TS_LEFT = 915, TS_RT = 143, TS_TOP = 129, TS_BOT = 931;

#define MINPRESSURE (200)
#define MAXPRESSURE (1000)

// Assign human-readable names to some common 16-bit color values:
#define BLACK (0x0000)
#define BLUE (0x001F)
#define RED (0xF800)
#define GREEN (0x07E0)
#define CYAN (0x07FF)
#define MAGENTA (0xF81F)
#define YELLOW (0xFFE0)
#define WHITE (0xFFFF)

// Control modes for encoder/joystick
#define DEFAULT_MODE (0)
#define RGB_LED_MODE (0)
#define LED_BAR_MODE (1)
#define LED_MATRIX_MODE (2)
#define LCD_MODE (3)
#define LAST_MODE (4)

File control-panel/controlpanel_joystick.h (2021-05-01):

#include <Adafruit_PCF8591.h>

namespace joystick
{
#define TILT_THRESHOLD 0.6

/**
 * @brief Enable debug messages printed on Serial port by defining
 * JOYSTICK_DEBUG directive.
 * 
 */
#undef JOYSTICK_DEBUG

    struct Coordinates
    {
        float X;
        float Y;
    };

    /**
     * @brief 
     * 
     */
    class Joystick
    {
    public:
        Joystick(Adafruit_PCF8591 *adc, uint8_t pinx, uint8_t piny);
        Joystick(uint8_t pinx, uint8_t piny);

        float getX(bool update_coords = true);
        float getY(bool update_coords = true);

        bool isTilted(float threshold = TILT_THRESHOLD, bool update_coords = true);
        int getDirection(float axis_coords, bool update_coords = true);

    protected:
        Coordinates coords = {0};
        void read();

    private:
        uint8_t pinx = 0;
        uint8_t piny = 0;
        Adafruit_PCF8591 *adc = NULL;

        float read_pin(uint8_t pin);
    };

    /**
     * @brief Construct a new Joystick:: Joystick object
     * 
     * @param adc 
     * @param pinx 
     * @param piny 
     */
    Joystick::Joystick(Adafruit_PCF8591 *adc, uint8_t pinx, uint8_t piny)
    {
        Joystick::adc = adc;
        Joystick::pinx = pinx;
        Joystick::piny = piny;
    }

    /**
     * @brief Construct a new Joystick:: Joystick object
     * 
     * @param pinx 
     * @param piny 
     */
    Joystick::Joystick(uint8_t pinx, uint8_t piny)
    {
        Joystick::pinx = pinx;
        Joystick::piny = piny;
    }

    /**
     * @brief Returns value corresponding to X-axis tilt of the joystick.
     * 
     * @param update_coords bool When set to true, read current tilt values from ADC first.
     * @return float X-axis tilt in range [-1..1]
     */
    float Joystick::getX(bool update_coords)
    {
        if (update_coords)
            Joystick::read();

        return Joystick::coords.X;
    }

    /**
     * @brief Returns value corresponding to Y-axis tilt of the joystick.
     * 
     * @param update_coords bool When set to true, read current tilt values from ADC first.
     * @return float Y-axis tilt in range [-1..1]
     */
    float Joystick::getY(bool update_coords)
    {
        if (update_coords)
            Joystick::read();

        return Joystick::coords.Y;
    }

    /**
     * @brief Returns true if joystick is fully tilted in either direction.
     * 
     * @param threshold float Value of threshold determine if joystick is tilted or not.
     * @param update_coords bool When set to true, read current tilt values from ADC first.
     * @return true Returned when joystick's tilt exceeds 0.6 in any direction.
     * @return false Returned whtn joystick's tile is below 0.6.
     */
    bool Joystick::isTilted(float threshold = TILT_THRESHOLD, bool update_coords = true)
    {
        bool isTilted = false;

        if (update_coords)
            Joystick::read();

        if (abs(Joystick::coords.X) > threshold or abs(Joystick::coords.Y) > threshold)
        {
            isTilted = true;
        }
#ifdef JOYSTICK_DEBUG
        Serial.print("\tJoystick isTilted=");
        Serial.print(isTilted);
        Serial.print(" threshold=");
        Serial.println(threshold);
#endif
        return isTilted;
    }

    /**
     * @brief Returns tilt direction in axis indicated by input parameter.
     * 
     * Checks if tilt of selected coordinates (X/Y) exceeds threshold,
     * returns integer indicating direction: 1 for up/left, -1 for down/right.
     * 
     * @param axis_coords One of joystick's coordinate values, in range [-1..1]
     * @param update_coords bool When set to true, read current tilt values from ADC first.
     * @return int Tilt direction: 1 for up/left, -1 for down/right, 0 for neutral postiion.
     */
    int Joystick::getDirection(float axis_coords, bool update_coords = true)
    {
        int direction = 0;
        if (update_coords)
            Joystick::read();

        if (abs(axis_coords) > TILT_THRESHOLD)
        {
            direction = (int)(axis_coords / abs(axis_coords));
#ifdef JOYSTICK_DEBUG
            Serial.print("\tJoystick direction=");
            Serial.println(direction);
#endif
        }
        return direction;
    }

    /**
     * @brief Reads current coordinats from joystick's pins and stores them.
     * 
     */
    void Joystick::read()
    {
        Joystick::coords.X = Joystick::read_pin(Joystick::pinx);
        Joystick::coords.Y = Joystick::read_pin(Joystick::piny);
#ifdef JOYSTICK_DEBUG
        Serial.print("\tJoystick X=");
        Serial.print(Joystick::coords.X);
        Serial.print(" Y=");
        Serial.println(Joystick::coords.Y);
#endif
    }

    /**
     * @brief Performs read of specified pin number and coverts value to [-1..1] range.
     * 
     * @param pin Pin number to read. Must be an analog in (either An pin of Arduino or ADC input pin number).
     * @return Joystick coordinates as read from pin.
     */
    float Joystick::read_pin(uint8_t pin)
    {
        float value = 0;

        auto convert = [](int value, uint16_t size) {
            float x = (((float)value / size) - 0.5) * 2;
            return x;
        };

        if (Joystick::adc != NULL)
        {
            uint8_t raw_val = Joystick::adc->analogRead(pin);
            value = convert(raw_val, UINT8_MAX);
        }
        else
        {
            int raw_val = analogRead(pin);
            value = convert(raw_val, 1024);
        }
        return value;
    }
}

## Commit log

2021-04-04 fixing pin assignment for keypad
    [control-panel.ino]
2021-04-11 cad file changes
    [kids-control-panel.kicad_pcb]
2021-04-11 Custome central panel PCB
    [central-panel-B_Cu.gbr, central-panel-B_Mask.gbr, central-panel-B_SilkS.gbr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]
2021-04-11 Ino sketch, working buttons and switches
2021-04-18 Adding modes, color selection, led bar support
2021-04-19 Assignment of pins to led bar breaks stuff
2021-04-21 Directory structure cleanup
    [central-panel-B_Cu.gbr, central-panel-B_Mask.gbr, central-panel-B_SilkS.gbr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]
2021-05-01 Fixing defines with parenthesis
    [controlpanel.h]
2021-05-02 Cleanup and resize of images and export collaterals
    [panel_do_wycinki_v2.dxf, panel_do_wycinki_v2_dxf_r12.dxf, panel_do_wycinki_v2_dxf_r14.dxf]
2021-05-03 Removing lingering comment in a header file. Downscaling images.
    [control-panel-power.sch, control_panel_power_delivery.sch, kids-control-panel-2.kicad_pcb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]
2021-11-26 Adding separate license to CAD files (CC BY 4.0)
